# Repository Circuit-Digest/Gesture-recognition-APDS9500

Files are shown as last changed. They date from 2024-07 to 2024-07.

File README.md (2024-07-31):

# DIY Gesture Recognition Module: Control Your Devices with a Wave
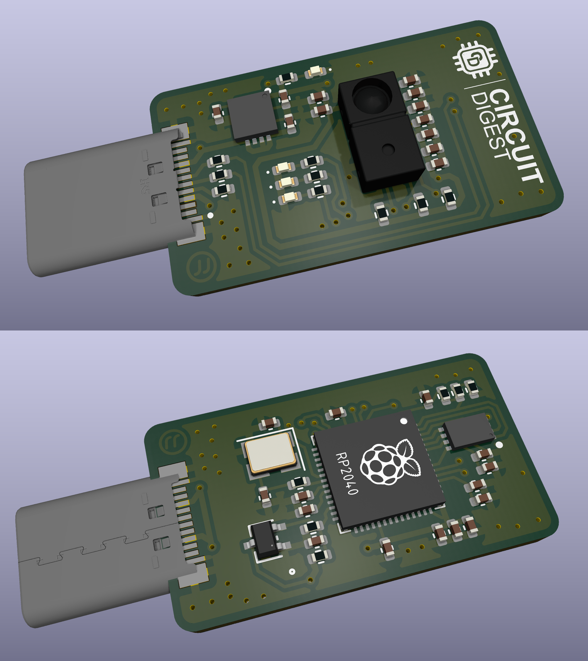
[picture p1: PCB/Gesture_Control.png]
image_tooltip

We have seen many types of control methods in electronic devices, including simple switches, rotary encoders, touch screens and even voice commands. Even though all of these methods work fine, we are always eager to try new methods for controlling our devices. One of which includes gesture recognition. Even the tech giant Google has been working on their own gesture recognition sensor named Project Soli. Inspired by that we have created our own gesture sensor. Our DIY module can be easily connected to a PC or Mac via a USB-C port, allowing you to control media playback, navigate applications, and perform any action that can be executed using a keyboard, all through intuitive gestures. 

For gesture sensing we are using the APDS-9500 sensor from Broadcom. It is an imaging-based gesture recognition IC with an I2C-bus interface. It can recognise nine gestures, including move up, move down, move left, move right, move forward, move backwards, circle-clockwise, circle-counterclockwise and wave. An RP2040 ARM SoC from the Raspberry Pi Foundation is being used as the main controller. When it is plugged in the RP2040 will enumerate an HID device and whenever a gesture is detected it will send a corresponding pre-programmed response to the PC using HID protocol. An ADM7171 ultra low noise LDO from Analog Devices is used for generating the 3.3V line for the SoC and the Sensor. To ensure the proper operation of the SoC we have also included an ADM803 voltage supervisor chip, which is also from Analog Devices.

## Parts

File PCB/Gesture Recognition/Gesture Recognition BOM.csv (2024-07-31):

Reference | Value | Datasheet | Footprint | Qty | DNP | DigiKey Link | DigiKey Part Number | Manufacturer | Manufacturer Product Number
BOOT1 | UBOOT | ~ | Resistor_SMD:R_0402_1005Metric | 1 | DNP
C1,C2,C5,C6,C7,C8,C9,C10,C11,C12,C14,C19,C24,C25 | 100n | ~ | Capacitor_SMD:C_0402_1005Metric | 14 |  | https://www.digikey.in/en/products/detail/murata-electronics/GRM155R71C104KA88J/2610892 | 490-6328-1-ND | Murata Electronics | GRM155R71C104KA88J
C3,C4,C13,C17,C22,C23,C27 | 1u | ~ | Capacitor_SMD:C_0402_1005Metric | 7 |  | https://www.digikey.in/en/products/detail/murata-electronics/GRM155R61E105MA12D/4905141 | 490-10018-1-ND | Murata Electronics | GRM155R61E105MA12D
C15,C16 | 18pF | ~ | Capacitor_SMD:C_0402_1005Metric | 2 |  | https://www.digikey.in/en/products/detail/murata-electronics/GRM1555C1H180JA01D/2854383 | 490-5858-1-ND | Murata Electronics | GRM1555C1H180JA01D
C18,C20 | 4.7uF | ~ | Capacitor_SMD:C_0402_1005Metric | 2 |  | https://www.digikey.in/en/products/detail/samsung-electro-mechanics/CL05A475MP5NRNC/3887140 | 1276-1482-1-ND | Samsung Electro-Mechanics | CL05A475MP5NRNC
C21 | 1n | ~ | Capacitor_SMD:C_0402_1005Metric | 1 |  | https://www.digikey.in/en/products/detail/murata-electronics/GRM1555C1H102JA01D/702509 | 490-3244-1-ND | Murata Electronics | GRM1555C1H102JA01D
C26 | 10uF | ~ | Capacitor_SMD:C_0402_1005Metric | 1 |  | https://www.digikey.in/en/products/detail/murata-electronics/GRM155R60J106ME05D/11500166 | 490-GRM155R60J106ME05DCT-ND | Manufacturer | GRM155R60J106ME05D
D2,D5 | LED Red | ~ | LED_SMD:LED_0402_1005Metric | 2 |  | https://www.digikey.in/en/products/detail/harvatek-corporation/B2841USD-20D001014U1930/16729514 | 3147-B2841USD-20D001014U1930CT-ND | Harvatek Corporation | B2841USD-20D001014U1930
D3 | LED Green | ~ | LED_SMD:LED_0402_1005Metric | 1 |  | https://www.digikey.in/en/products/detail/harvatek-corporation/B2841NG-05D000514U1930/16729536 | 3147-B2841NG--05D000514U1930CT-ND | Harvatek Corporation | B2841NG--05D000514U1930
D4 | LED Blue | ~ | LED_SMD:LED_0402_1005Metric | 1 |  | https://www.digikey.in/en/products/detail/harvatek-corporation/B2841NB-20C001414U1930/16729522 | 3147-B2841NB--20C001414U1930CT-ND | Harvatek Corporation | B2841NB--20C001414U1930
IC1 | ADM7171ACPZ-3.3-R7 | http://www.analog.com/media/en/technical-documentation/data-sheets/ADM7171.pdf | ADM7171ACPZ-3.3-R7:SON50P300X300X80-9N-D | 1 |  | https://www.digikey.in/en/products/detail/analog-devices-inc/ADM7171ACPZ-3-3-R7/5011539 | 505-ADM7171ACPZ-3.3-R7CT-ND | Analog Devices | ADM7171ACPZ-3.3-R7
J1 | CX60-24S-UNIT |  | CX60_24S_UNIT:HIROSE_CX60-24S-UNIT | 1 |  | https://www.digikey.in/en/products/detail/hirose-electric-co-ltd/CX60-24S-UNIT/8561505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 | H126317-ND | Hirose Electric Co Ltd | CX60-24S-UNIT
R1,R4,R6,R15 | 10k | ~ | Resistor_SMD:R_0402_1005Metric | 4 |  | https://www.digikey.in/en/products/detail/panasonic-electronic-components/ERJ-2RKF1002X/192073 | P10.0KLCT-ND | Panasonic Electronic Components | ERJ-2RKF1002X
R2,R3,R9,R10,R17,R18 | 1k | ~ | Resistor_SMD:R_0402_1005Metric | 6 |  | https://www.digikey.in/en/products/detail/panasonic-electronic-components/ERJ-2RKF1001X/79729 | P1.00KLCT-ND | Panasonic Electronic Components | ERJ-2RKF1001X
R5 | DNP | ~ | Resistor_SMD:R_0402_1005Metric | 1 | DNP
R7,R8 | 27R | ~ | Resistor_SMD:R_0402_1005Metric | 2 |  | https://www.digikey.in/en/products/detail/panasonic-electronic-components/ERJ-2RKF27R0X/1746179 | P27.0LCT-ND | Panasonic Electronic Components | ERJ-2RKF27R0X
R11 | 5.1k | ~ | Resistor_SMD:R_0402_1005Metric | 1 |  | https://www.digikey.in/en/products/detail/panasonic-electronic-components/ERJ-2GEJ512X/147044 | P5.1KJCT-ND | Panasonic Electronic Components | ERJ-2GEJ512X
RST1 | RST | ~ | Resistor_SMD:R_0402_1005Metric | 1 | DNP
U1 | RP2040 | https://datasheets.raspberrypi.org/rp2040/rp2040-datasheet.pdf | RP2040:RP2040-QFN-56 | 1 |  | https://www.digikey.in/en/products/detail/raspberry-pi/SC0914-13/14306010?s=N4IgTCBcDaIEoAUwAYAsyQF0C%2BQ | 2648-SC0914(13)CT-ND | Raspberry Pi | SC0914(13)
U2 | W25Q16JVUXIQ_TR | https://componentsearchengine.com/Datasheets/1/W25Q16JVUXIQ TR.pdf | SON50P300X200X60-9N | 1 |  | https://www.digikey.in/en/products/detail/winbond-electronics/W25Q16JVUXIQ-TR/15182017 | 256-W25Q16JVUXIQTRCT-ND | Winbond
U3 | APDS-9500 |  | APDS-9500:ADPS-9500 | 1 |  | https://www.digikey.in/en/products/detail/broadcom-limited/APDS-9500/6685410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 | 516-3579-1-ND | Broadcom Limited | APDS-9500
U4 | ADM803SAKSZ-REEL7 | ADM803SAKSZ-REEL7 | ADM803SAKSZ:KS_3_ADI | 1 |  | https://www.digikey.in/en/products/detail/analog-devices-inc/ADM803SAKSZ-REEL7/995374 | 505-ADM803SAKSZ-REEL7CT-ND | Analog Devices Inc. | ADM803SAKSZ-REEL7
Y1 | YIC-12M20P2/XT324-10/10 | ~ | Crystal:Crystal_SMD_3225-4Pin_3.2x2.5mm | 1 |  | https://www.digikey.in/en/products/detail/raltron-electronics/RH100-12-000-18-2030-EXT-TR/10272648 | 2151-RH100-12.000-18-2030-EXT-TRCT-ND | Raltron Electronics | RH100-12.000-18-2030-EXT-TR

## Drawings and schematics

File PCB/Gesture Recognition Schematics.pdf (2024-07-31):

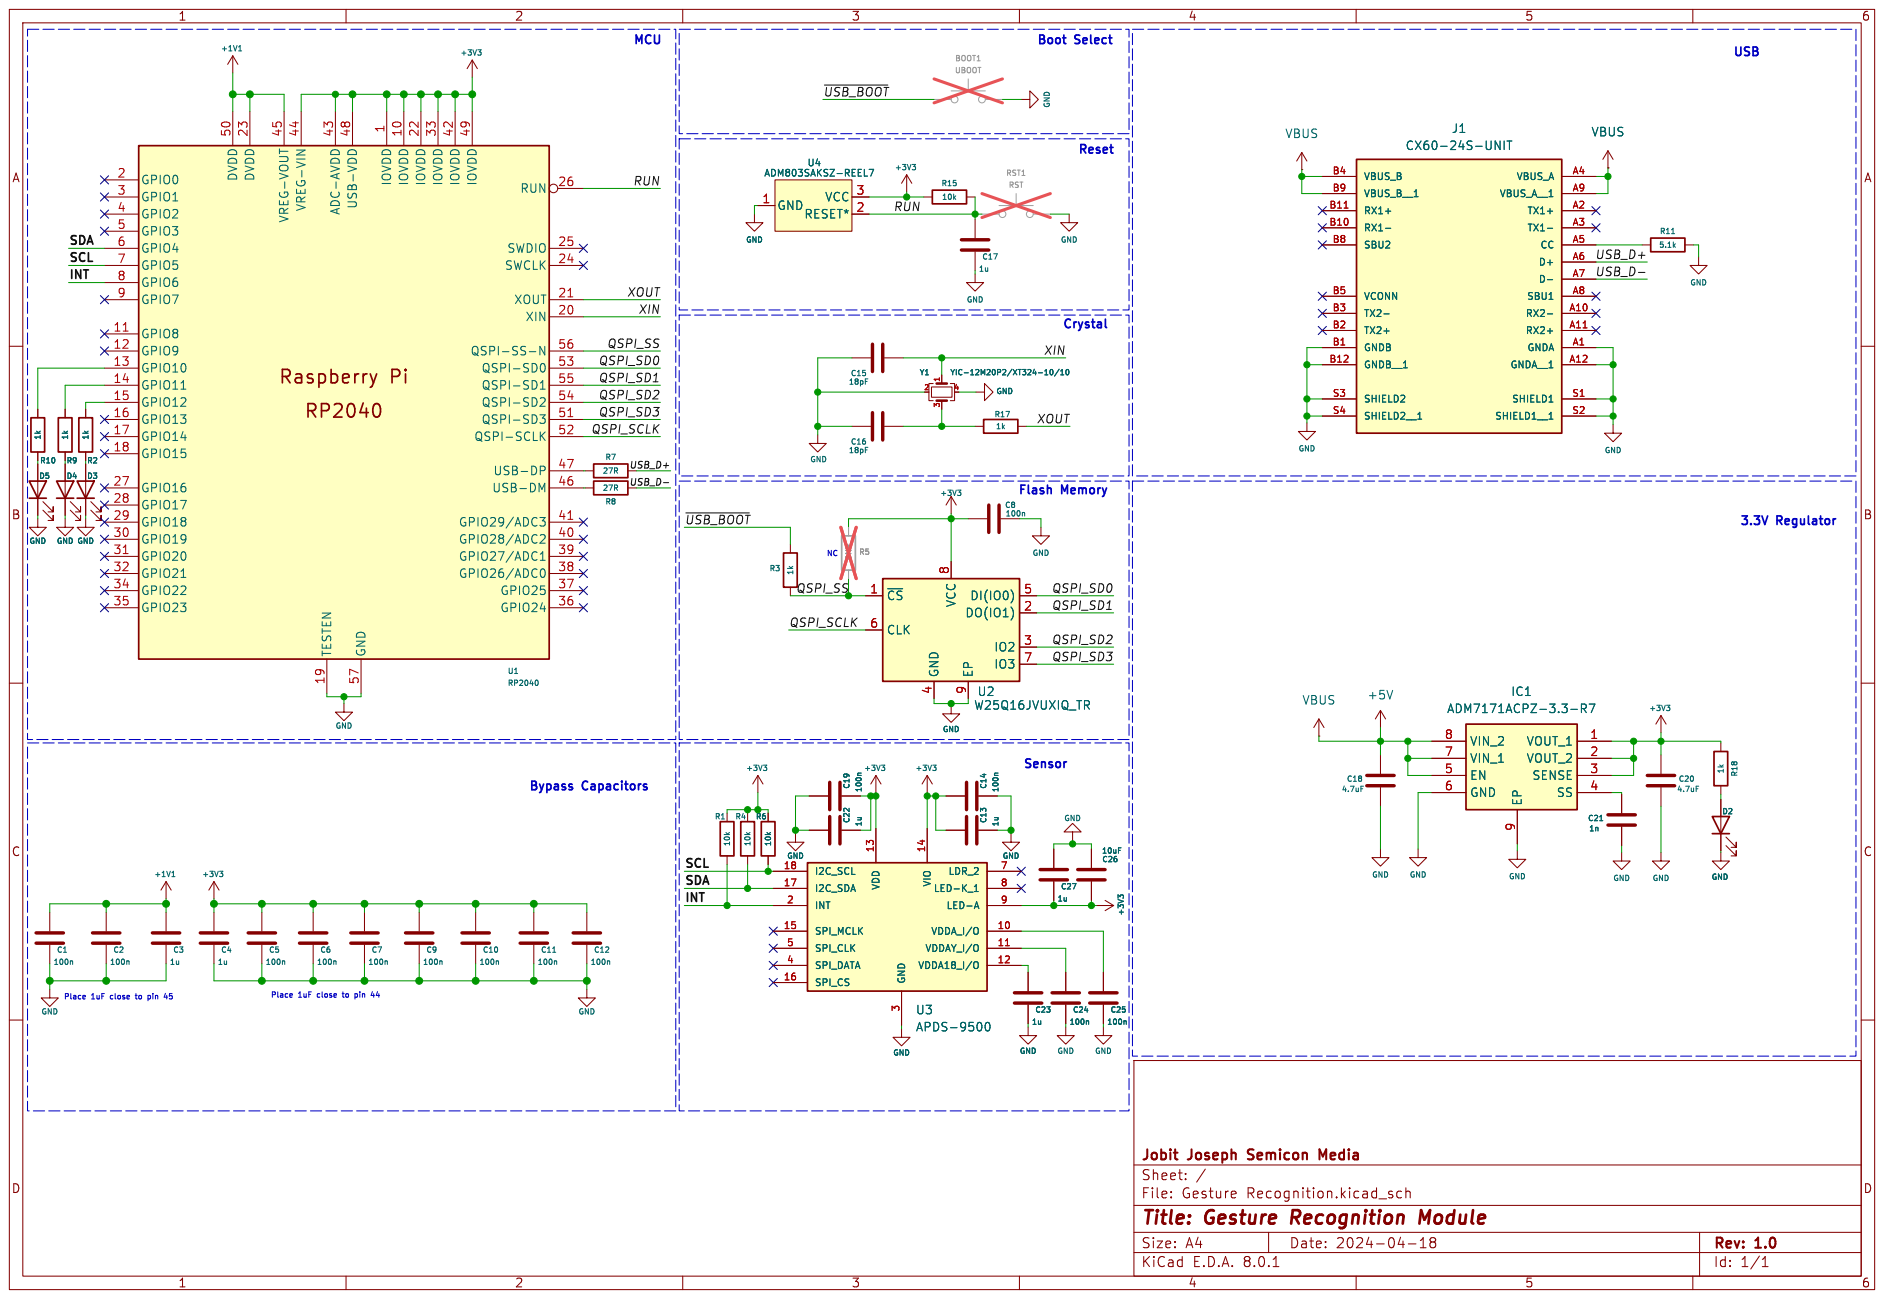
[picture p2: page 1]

1 IOVDD 10 GPIO8 11 GPIO9 12 GPIO10 13 GPIO11 14 GPIO12 15 GPIO13 16 GPIO14 17 GPIO15 18 TESTEN 19 GPIO0 2 XIN 20 XOUT 21 IOVDD 22 DVDD 23 SWCLK 24 SWDIO 25 RUN 26 GPIO16 27 GPIO17 28 GPIO18 29 GPIO1 3 GPIO19 30 GPIO20 31 GPIO21 32 IOVDD 33 GPIO22 34 GPIO23 35 GPIO24 36 GPIO25 37 GPIO26/ADC0 38 GPIO27/ADC1 39 GPIO2 4 GPIO28/ADC2 40 GPIO29/ADC3 41 IOVDD 42 ADC-AVDD 43 VREG-VIN 44 VREG-VOUT 45 USB-DM 46 USB-DP 47 USB-VDD 48 IOVDD 49 GPIO3 5 DVDD 50 QSPI-SD3 51 QSPI-SCLK 52 QSPI-SD0 53 QSPI-SD2 54 QSPI-SD1 55 QSPI-SS-N 56 GND 57 GPIO4 6 GPIO5 7 GPIO6 8 GPIO7 9

Place 1uF close to pin 45

Id: 1/1 Title: Gesture Recognition Module

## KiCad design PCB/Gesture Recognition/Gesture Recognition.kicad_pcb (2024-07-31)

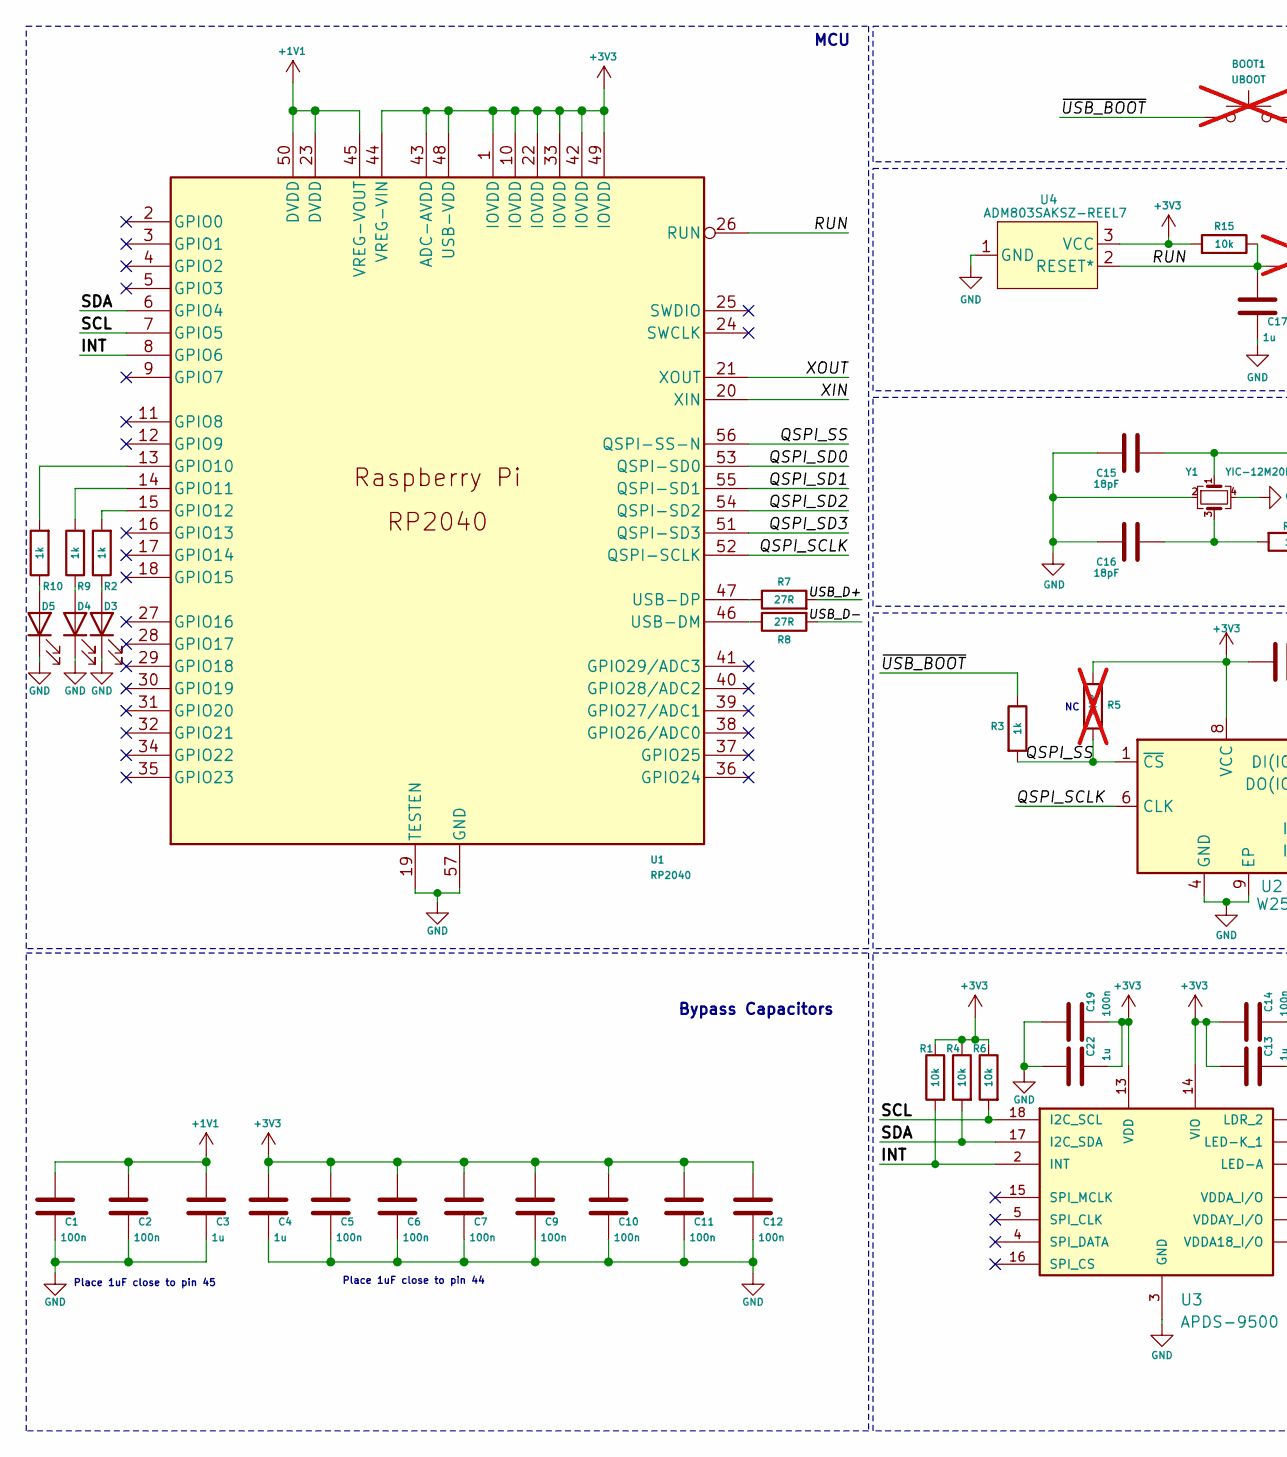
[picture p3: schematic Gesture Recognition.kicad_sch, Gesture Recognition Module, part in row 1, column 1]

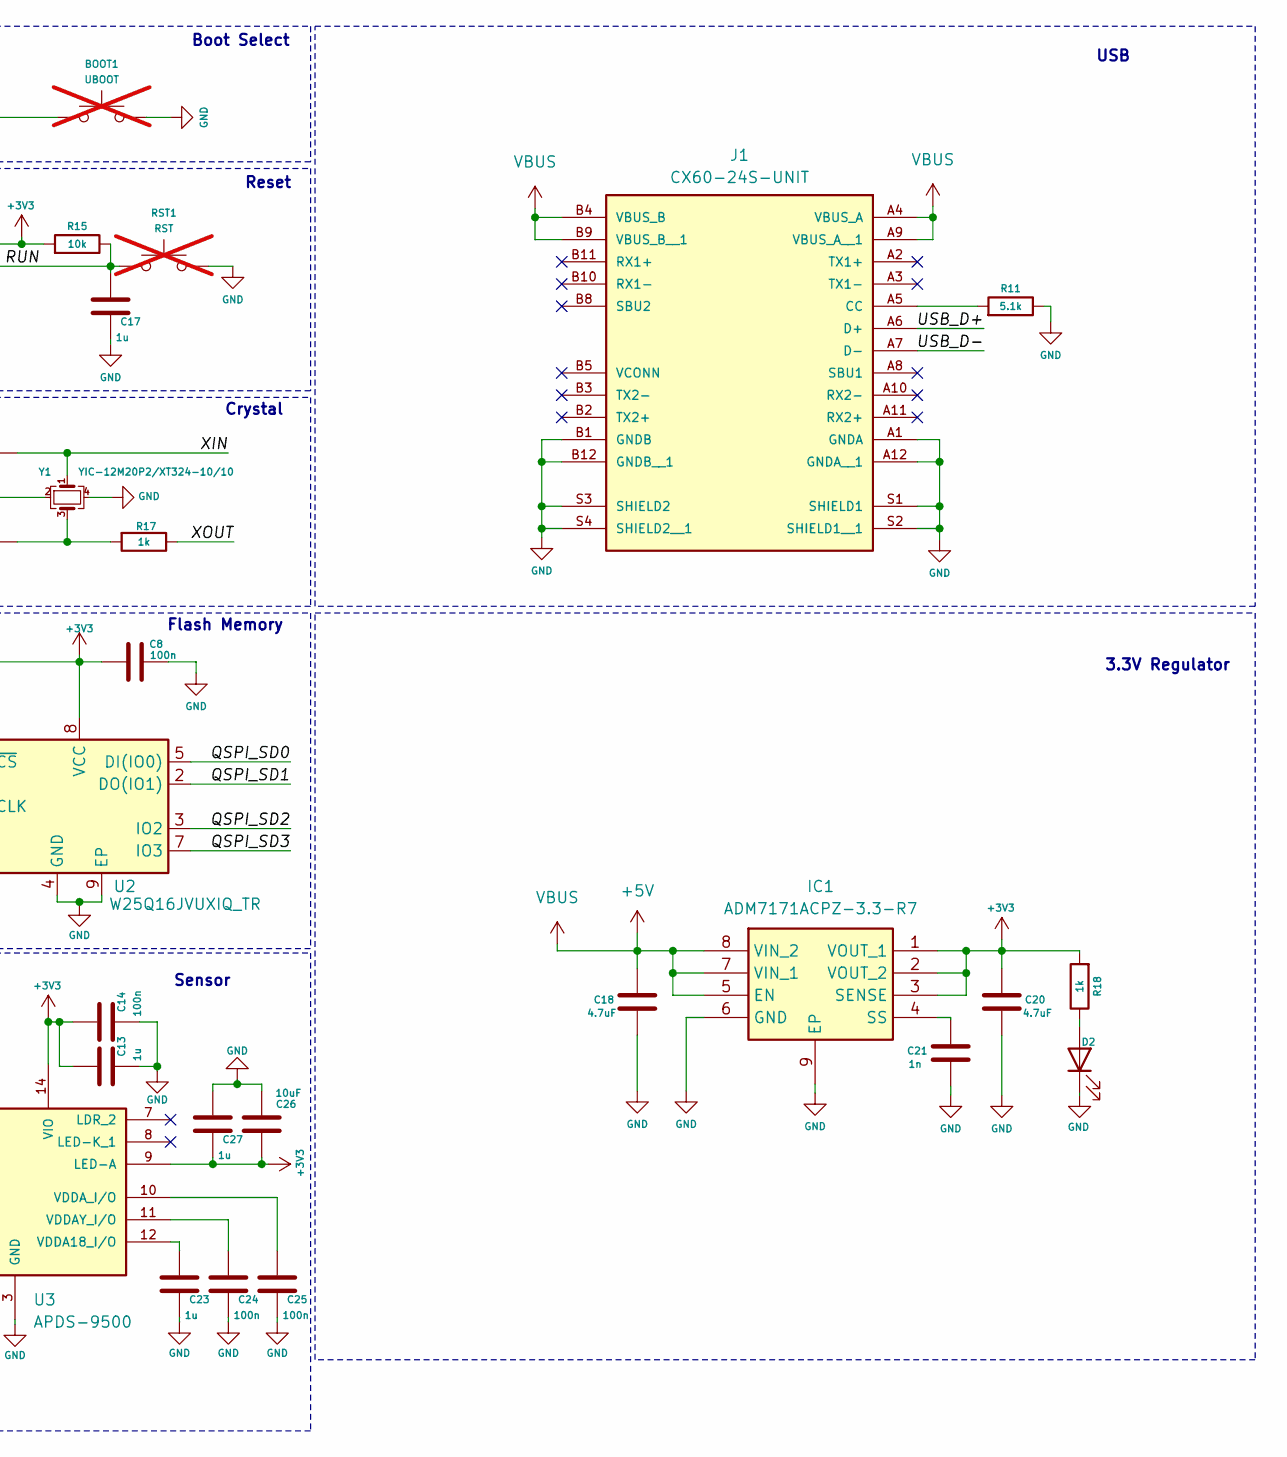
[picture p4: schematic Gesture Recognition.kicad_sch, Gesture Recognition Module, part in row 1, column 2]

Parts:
BOOT1: UBOOT; R_0402_1005Metric; not fitted
C1, C2, C5, C6, C7, C8, C9, C10, C11, C12, C14, C19, C24, C25: 100n; C_0402_1005Metric; DigiKey Part Number 490-6328-1-ND
C3, C4, C13, C17, C22, C23, C27: 1u; C_0402_1005Metric; DigiKey Part Number 490-10018-1-ND
C15, C16: 18pF; C_0402_1005Metric; DigiKey Part Number 490-5858-1-ND
C18, C20: 4.7uF; C_0402_1005Metric; DigiKey Part Number 1276-1482-1-ND
C21: 1n; C_0402_1005Metric; DigiKey Part Number 490-3244-1-ND
C26: 10uF; C_0402_1005Metric; DigiKey Part Number 490-GRM155R60J106ME05DCT-ND
D2, D5: LED Red; LED_0402_1005Metric; DigiKey Part Number 3147-B2841USD-20D001014U1930CT-ND
D3: LED Green; LED_0402_1005Metric; DigiKey Part Number 3147-B2841NG--05D000514U1930CT-ND
D4: LED Blue; LED_0402_1005Metric; DigiKey Part Number 3147-B2841NB--20C001414U1930CT-ND
IC1: ADM7171ACPZ-3.3-R7; SON50P300X300X80-9N-D; DigiKey Part Number 505-ADM7171ACPZ-3.3-R7CT-ND
J1: CX60-24S-UNIT; HIROSE_CX60-24S-UNIT; PARTREV 5; DigiKey Part Number H126317-ND
R1, R4, R6, R15: 10k; R_0402_1005Metric; DigiKey Part Number P10.0KLCT-ND
R2, R3, R9, R10, R17, R18: 1k; R_0402_1005Metric; DigiKey Part Number P1.00KLCT-ND
R5: DNP; R_0402_1005Metric; not fitted
R7, R8: 27R; R_0402_1005Metric; DigiKey Part Number P27.0LCT-ND
R11: 5.1k; R_0402_1005Metric; DigiKey Part Number P5.1KJCT-ND
RST1: RST; R_0402_1005Metric; not fitted
U1: RP2040; RP2040-QFN-56; DigiKey Part Number 2648-SC0914(13)CT-ND
U2: W25Q16JVUXIQ_TR; SON50P300X200X60-9N; DigiKey Part Number 256-W25Q16JVUXIQTRCT-ND
U3: APDS-9500; ADPS-9500; DigiKey Part Number 516-3579-1-ND
U4: ADM803SAKSZ-REEL7; KS_3_ADI; DigiKey Part Number 505-ADM803SAKSZ-REEL7CT-ND
Y1: YIC-12M20P2/XT324-10/10; Crystal_SMD_3225-4Pin_3.2x2.5mm; DigiKey Part Number 2151-RH100-12.000-18-2030-EXT-TRCT-ND

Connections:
+1V1: C1.1, C2.1, C3.1, U1.23 (DVDD), U1.45 (VREG-VOUT), U1.50 (DVDD)
+3V3: C4.1, C5.1, C6.1, C7.1, C8.1, C9.1, C10.1, C11.1, C12.1, C13.1, C14.1, C19.2, C20.2, C22.2, C26.1, C27.2, IC1.1 (VOUT_1), IC1.2 (VOUT_2), IC1.3 (SENSE), R1.1, R4.1, R5.1, R6.1, R15.2, R18.2, U1.1 (IOVDD), U1.10 (IOVDD), U1.22 (IOVDD), U1.33 (IOVDD), U1.42 (IOVDD), U1.43 (ADC-AVDD), U1.44 (VREG-VIN), U1.48 (USB-VDD), U1.49 (IOVDD), U2.8 (VCC), U3.9 (LED-A), U3.13 (VDD), U3.14 (VIO), U4.3 (VCC)
+5V: C18.2, IC1.5 (EN), IC1.7 (VIN_1), IC1.8 (VIN_2), J1.A4 (VBUS_A), J1.A9 (VBUS_A__1), J1.B4 (VBUS_B), J1.B9 (VBUS_B__1)
/INT: R1.2, U1.8 (GPIO6), U3.2 (INT)
/QSPI_SCLK: U1.52 (QSPI-SCLK), U2.6 (CLK)
/QSPI_SD0: U1.53 (QSPI-SD0), U2.5 (DI(IO0))
/QSPI_SD1: U1.55 (QSPI-SD1), U2.2 (DO(IO1))
/QSPI_SD2: U1.54 (QSPI-SD2), U2.3 (IO2)
/QSPI_SD3: U1.51 (QSPI-SD3), U2.7 (IO3)
/QSPI_SS: R3.2, R5.2, U1.56 (QSPI-SS-N), U2.1 (~CS)
/RUN: C17.1, R15.1, RST1.1, U1.26 (RUN), U4.2 (RESET*)
/SCL: R6.2, U1.7 (GPIO5), U3.18 (I2C_SCL)
/SDA: R4.2, U1.6 (GPIO4), U3.17 (I2C_SDA)
/USB_D+: J1.A6 (D+), R7.2
/USB_D-: J1.A7 (D-), R8.2
/XIN: C15.1, U1.20 (XIN), Y1.1
/XOUT: R17.1, U1.21 (XOUT)
/~USB_BOOT: BOOT1.1, R3.1
GND: BOOT1.2, C1.2, C2.2, C3.2, C4.2, C5.2, C6.2, C7.2, C8.2, C9.2, C10.2, C11.2, C12.2, C13.2, C14.2, C15.2, C16.2, C17.2, C18.1, C19.1, C20.1, C21.1, C22.1, C23.2, C24.2, C25.2, C26.2, C27.1, D2.1 (K), D3.1 (K), D4.1 (K), D5.1 (K), IC1.6 (GND), IC1.9 (EP), J1.A1 (GNDA), J1.A12 (GNDA__1), J1.B1 (GNDB), J1.B12 (GNDB__1), J1.S1 (SHIELD1), J1.S2 (SHIELD1__1), J1.S3 (SHIELD2), J1.S4 (SHIELD2__1), R11.1, RST1.2, U1.19 (TESTEN), U1.57 (GND), U2.4 (GND), U2.9 (EP), U3.3 (GND), U4.1 (GND), Y1.2, Y1.4
unnamed: C16.1, R17.2, Y1.3
unnamed: D2.2 (A), R18.1
unnamed: D3.2 (A), R2.1
unnamed: D4.2 (A), R9.1
unnamed: D5.2 (A), R10.1
unnamed: C21.2, IC1.4 (SS)
unnamed: J1.A5 (CC), R11.2
unnamed: R10.2, U1.13 (GPIO10)
unnamed: R9.2, U1.14 (GPIO11)
unnamed: R2.2, U1.15 (GPIO12)
unnamed: R8.1, U1.46 (USB-DM)
unnamed: R7.1, U1.47 (USB-DP)
unnamed: C23.1, U3.12 (VDDA18_I/O)
unnamed: C24.1, U3.11 (VDDAY_I/O)
unnamed: C25.1, U3.10 (VDDA_I/O)

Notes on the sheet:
Reset
MCU
Place 1uF close to pin 45
Crystal
USB
Flash Memory
Boot Select
Place 1uF close to pin 44
Sensor
3.3V Regulator
Bypass Capacitors

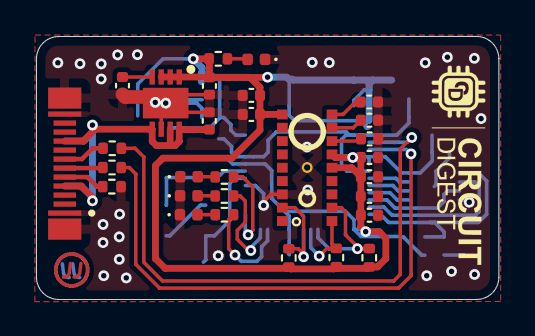
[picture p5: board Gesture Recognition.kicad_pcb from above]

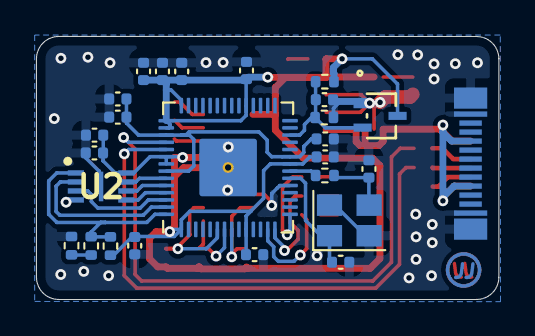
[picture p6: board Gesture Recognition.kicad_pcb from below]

Board: 2 copper layers, 25.7 x 14.6 mm, 54 parts (25 on the bottom side), 34 nets.

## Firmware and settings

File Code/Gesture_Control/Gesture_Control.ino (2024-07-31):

/*

 * Project Name: Geasture Control Module 

 * Project Brief: Firmware for Geasture Control Module

 * Author: Jobit Joseph

 * Copyright © Jobit Joseph

 * Copyright © Semicon Media Pvt Ltd

 * Copyright © Circuitdigest.com

 * 

 * This program is free software: you can redistribute it and/or modify

 * it under the terms of the GNU General Public License as published by

 * the Free Software Foundation, in version 3.

 *

 * This program is distributed in the hope that it will be useful,

 * but WITHOUT ANY WARRANTY; without even the implied warranty of

 * MERCHANTABILITY or FITNESS FOR A PARTICULAR PURPOSE. See the

 * GNU General Public License for more details.

 *

 * You should have received a copy of the GNU General Public License

 * along with this program. If not, see <http://www.gnu.org/licenses/&gt;.

 *

 */
#include <Wire.h>
#include <Adafruit_APDS9500.h>
#include <Keyboard.h>
#define Red 10
#define Blue 11
#define Green 12
Adafruit_APDS9500 apds;
const unsigned long onInterval = 100; 
const unsigned long offInterval = 1000;
unsigned long previousMillis = 0;
bool ledState = LOW;

unsigned long ledBlinkMillis = 0;
const unsigned long blinkInterval = 200; // Blink interval in milliseconds
bool ledBlinkState = LOW;
bool shouldBlink = false; //

void ledCB(bool numlock, bool capslock, bool scrolllock, bool compose, bool kana, void *cbData) {
  (void)numlock;
  (void)scrolllock;
  (void)compose;
  (void)kana;
  (void)cbData;
  digitalWrite(Green, capslock ? HIGH : LOW);
}


void setup(void) {
  pinMode(Red, OUTPUT);
  pinMode(Blue, OUTPUT);
  pinMode(Green, OUTPUT);
  digitalWrite(Red, 0);
  digitalWrite(Green, 0);
  digitalWrite(Blue, ledState);
  Serial.begin(115200);
  Keyboard.onLED(ledCB);
  Keyboard.begin();
  //while (!Serial) delay(10);     // will pause Zero, Leonardo, etc until serial console opens

  Serial.println("Adafruit APDS9500 test!");

  while (!apds.begin()) {
    Serial.println("Failed to find APDS9500 chip, retrying...");
    delay(1000);  // Delay for 1 second before retrying
  }
  Serial.println("APDS9500 Found!");
}

void loop() {

  uint16_t gesture_flags = apds.getDetectedGestures();
  // Check if sensor read was unsuccessful
  if (gesture_flags == (uint16_t)-1) {
    Serial.println("Sensor read failed, attempting to reinitialize...");
    while (!apds.begin()) {
      Serial.println("Failed to reinitialize APDS9500, retrying...");
      delay(1000);  // Delay for 1 second before retrying
    }
    Serial.println("APDS9500 reinitialized successfully.");
    return;  // Return to the start of the loop after reinitialization
  }
  if (gesture_flags != 0) { // If any gesture is detected, start blinking
    shouldBlink = true;
    ledBlinkMillis = millis(); // Reset the blink timer
  }

  if (shouldBlink) {
    unsigned long currentMillis = millis();
    if (currentMillis - ledBlinkMillis >= blinkInterval) {
      ledBlinkState = !ledBlinkState;
      digitalWrite(Green, ledBlinkState);
      digitalWrite(Red, ledBlinkState);
      ledBlinkMillis = currentMillis;
      if (!ledBlinkState) { // Stop blinking after one cycle
        shouldBlink = false;
      }
    }
  }

  if (gesture_flags & 0x01)
  {
    Serial.println("Down event detected");
    Keyboard.write(KEY_DOWN_ARROW);
  } 
  if (gesture_flags & 0x02){
     Serial.println("Up event detected");
    Keyboard.write(KEY_UP_ARROW);
  }
  if (gesture_flags & 0x04){
    Serial.println("Right event detected");
    Keyboard.write(KEY_RIGHT_ARROW);
  }
  if (gesture_flags & 0x08){
    Serial.println("Left event detected");
    Keyboard.write(KEY_LEFT_ARROW);
  }

  char key_space = ' ';
  if (gesture_flags & 0x10){
    Serial.println("FORWARD event detected");
    Keyboard.write(key_space);
  }
  if (gesture_flags & 0x20)
  {  
    Serial.println("BACKWARD event detected");
  } 

  if (gesture_flags & 0x40) Serial.println("CLOCKWISE event detected");
  if (gesture_flags & 0x80) Serial.println("COUNTERCLOCKWISE event detected");

  if ((gesture_flags >> 8) & 0x01) Serial.println("WAVE event detected");
  if ((gesture_flags >> 8) & 0x02) Serial.println("PROXIMITY event detected");
  if ((gesture_flags >> 8) & 0x04) Serial.println("HAS OBJECT event detected");
  if ((gesture_flags >> 8) & 0x08) Serial.println("WAKE UP TRIGGER event detected");
  if ((gesture_flags >> 8) & 0x80) Serial.println("NO OBJECT event detected");

  unsigned long currentMillis = millis();
  unsigned long interval = ledState ? onInterval : offInterval;
  if (currentMillis - previousMillis >= interval) {
    previousMillis = currentMillis;
    ledState = !ledState;
    digitalWrite(Blue, ledState);
  }
  delay(100);
}

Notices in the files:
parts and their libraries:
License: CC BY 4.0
